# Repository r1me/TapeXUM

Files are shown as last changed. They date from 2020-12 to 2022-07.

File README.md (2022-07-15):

# TapeXUM
TapeXUM is a USB device that can read and write to cassettes of Commodore 16/64/VIC-20 (read and write) and ZX Spectrum (read only) format. It requires a Commodore datasette connected to it. This project is based on ZoomTape by Arnd Menge, a great idea and originally a part of OpenCBM package. TapeXUM uses Arduino Pro Micro and through hole components so it's a DIY friendly design.  
Huge thanks to Data/Tropyx for creating enclosure design for 3D printing!  

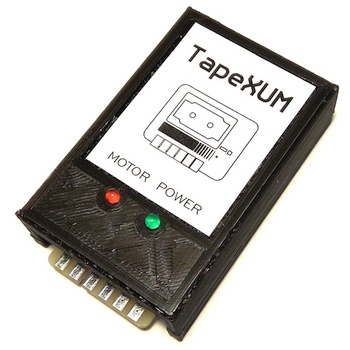
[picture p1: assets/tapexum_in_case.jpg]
TapeXUM in case


### Changes in software (since ZoomTape)
- modified device firmware to support Arduino Pro Micro
- added ability to continue tape capture even if stopped (before that, read was interrupted once datasette playback had stopped i.e. with Stop button)
- added azimuth adjustment feature (prepare your screwdriver)

### BOM
| Component  | qty |
| --- | --- |
| Arduino Pro Micro 5V | 1 |
| 1/4W Resistor for LEDs (~1K, depending on your preference) | 2 |
| 1/4W 1K Resistor | 1 |
| 1/2W 1.5k Resistor | 1 |
| 2N3904 Transistor | 1 |
| 2SD880 or 2SD313 Transistor | 1 |
| 3mm LED (i.e. green and red) | 2 |
| 6V8 Zener diode | 1 |
| 1N400x diode | 1 |
| 1uF electrolytic capacitor | 1 |
| 0.1uF electrolytic capacitor | 1 |
| Barrel jack DC connector 2.1/5.5mm or 2.5/5.5mm | 1 |
| 1x3 pin header 2.54mm and a jumper | 1 |
| 9VDC 500mA power supply with DC connector (center positive) | 1 |
| Micro USB cable | 1 |

### Download
Windows 7/10 64-bit libraries and tools: https://github.com/r1me/TapeXUM/releases/download/1.0/xum-installer-x64.zip  
Get PCB's from PCBWay: https://www.pcbway.com/project/shareproject/TapeXUM___Capture_and_write_Commodore_tapes_via_USB_device.html   
Gerber and Kicad files (hardware design): https://github.com/r1me/TapeXUM/tree/main/hardware  
Firmware for Arduino Pro Micro: https://github.com/r1me/TapeXUM/tree/main/firmware  
3D enclosure: https://www.thingiverse.com/thing:4659235  
OpenCBM: https://github.com/r1me/OpenCBM  

### Programming Arduino
`avrdude -p m32u4 -c avr109 -P comX -U flash:w:xum1541-PROMICRO_TAPE-v08.hex`

### License
TapeXUM follows same license for software as OpenCBM. PCB design of TapeXUM is free and shared under CERN OHW v2 (open hardware licence).

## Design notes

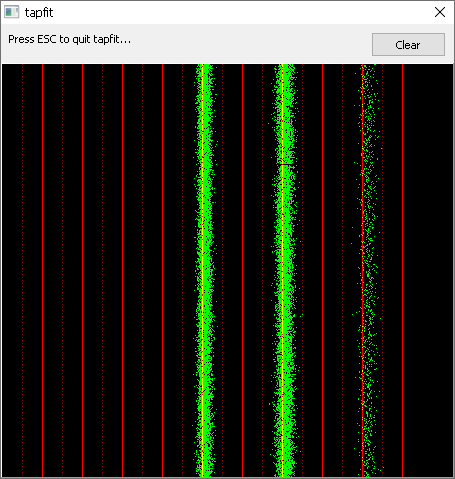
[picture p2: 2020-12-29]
assets/tapfit.png

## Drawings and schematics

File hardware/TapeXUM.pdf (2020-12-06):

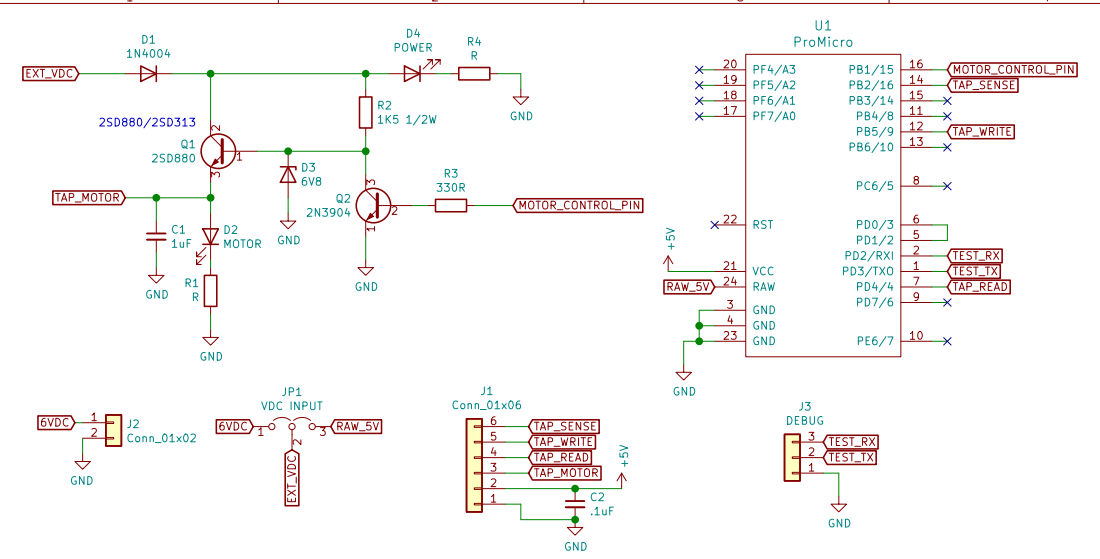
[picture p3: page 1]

File: TapeXUM.sch Sheet: / rime

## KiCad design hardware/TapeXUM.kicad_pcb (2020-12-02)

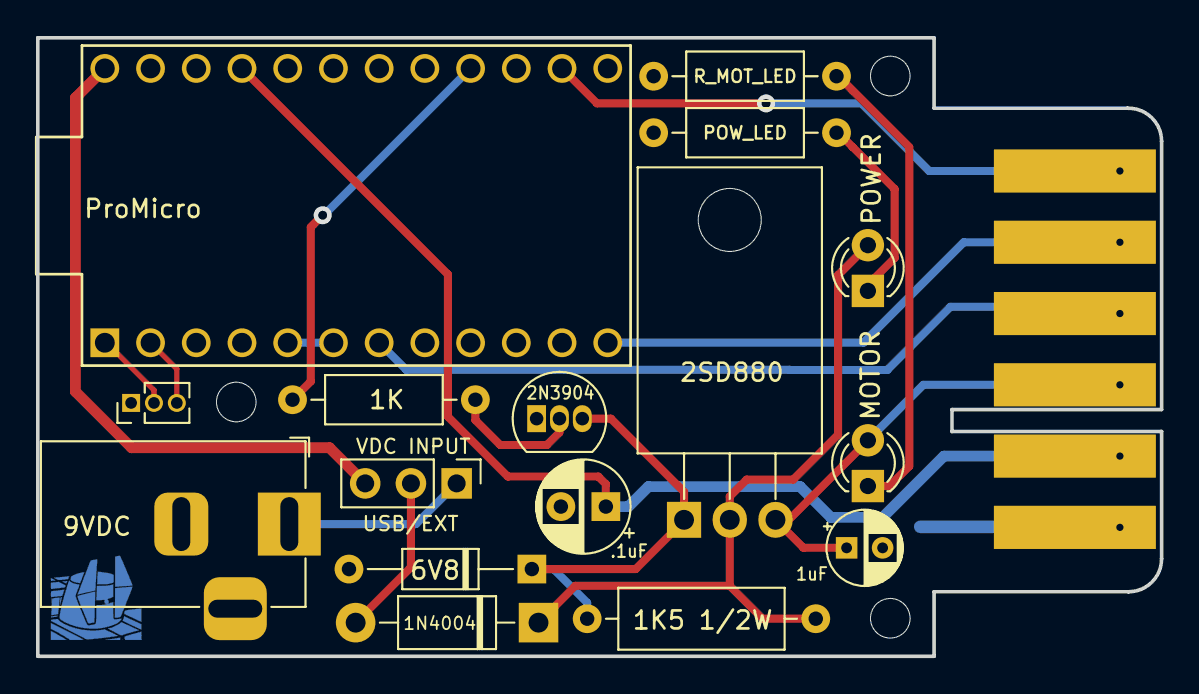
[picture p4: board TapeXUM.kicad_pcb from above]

Board: 2 copper layers, 62.4 x 34.4 mm, 17 parts (0 on the bottom side), 18 nets.

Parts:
C1: 1uF; CP_Radial_D4.0mm_P2.00mm
C2: .1uF; CP_Radial_D5.0mm_P2.50mm
D1: 1N4004; D_DO-41_SOD81_P10.16mm_Horizontal
D2: MOTOR; LED_D3.0mm
D3: 6V8; D_DO-35_SOD27_P10.16mm_Horizontal
D4: POWER; LED_D3.0mm
J1: Conn_01x06; conn_datasette2
J2: Conn_01x02; BarrelJack_Horizontal
J3: DEBUG; PinHeader_1x03_P1.27mm_Vertical
JP1: VDC INPUT; PinHeader_1x03_P2.54mm_Vertical
Q1: 2SD880; TO-220-3_Horizontal_TabDown
Q2: 2N3904; TO-92_Inline
R1, R4: R; R_Axial_DIN0207_L6.3mm_D2.5mm_P10.16mm_Horizontal
R2: 1K5 1/2W; R_Axial_DIN0309_L9.0mm_D3.2mm_P12.70mm_Horizontal
R3: 330R; R_Axial_DIN0207_L6.3mm_D2.5mm_P10.16mm_Horizontal
U1: ProMicro

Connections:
6VDC: J2.1, JP1.1
+5V: C2.1, J1.2, U1.21
EXT_VDC: D1.2, JP1.2
GND: C1.2, C2.2, D3.2, J1.1, J2.2, J3.1, Q2.1, R1.1, R4.1, U1.3, U1.4, U1.23
MOTOR_CONTROL_PIN: R3.1, U1.16
unnamed: D1.1, D4.2, Q1.2, R2.1
unnamed: D2.1, R1.2
unnamed: D3.1, Q1.1, Q2.3, R2.2
unnamed: D4.1, R4.2
unnamed: Q2.2, R3.2
unnamed: U1.5, U1.6
RAW_5V: JP1.3, U1.24
TAP_MOTOR: C1.1, D2.2, J1.3, Q1.3
TAP_READ: J1.4, U1.7
TAP_SENSE: J1.6, U1.14
TAP_WRITE: J1.5, U1.12
TEST_RX: J3.3, U1.2
TEST_TX: J3.2, U1.1

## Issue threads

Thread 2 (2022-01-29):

What is behind this crazy idea of use 0.1 uF electrolytic capacitor?

mesmariusz, 2022-01-29:
Hi :-)

What is behind this crazy idea of use 0.1 uF electrolytic capacitor?
[https://i.imgur.com/Gs0jLsC.png](https://i.imgur.com/Gs0jLsC.png)
[https://i.imgur.com/7Lc5MwK.png](https://i.imgur.com/7Lc5MwK.png)

Why didn't you use just standard unpolarized capacitor e.g. 100 nF / 50V ?

Is there seriously any reason to use 0.1 uF electrolytic capacitor?

mesmariusz, 2022-03-11:
Anybody here?

May I use just common unpolarised 100nF instead of electrolytic 0.1 uF ?

mesmariusz, 2022-03-16:
Ok, thank you very much for your feedback.

Closed 2022-03-16.

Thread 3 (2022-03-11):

Available .hex vs Pro-Micro-ATmega32U4-5-V-16-MHz - should it work on this hardware ?

mesmariusz, 2022-03-11:
Should the firmware:
https://github.com/r1me/TapeXUM/tree/main/firmware

work with this module:
https://shopee.pl/Baipestotoy-Pro-Micro-ATmega32U4-5-V-16-MHz-Wymie%C5%84-ATmega328-Arduino-Pro-Mini-i.550891774.12958189188

Is / should be the uC on this module compatibile with this .hex ?

r1me, 2022-03-16:
Hey, yes that's a right footprint Arduino Pro Micro (there are few other versions that wouldn't fit). The one you've linked will work correctly for this project.

Closed 2022-03-16.

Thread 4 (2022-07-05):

Any recommended way to flash .hex file to Arduino Pro Micro (Leonardo) ?

mesmariusz, 2022-07-05:
Hi.

Is there any recommended way to program .hex file to Arduino Pro Micro (Leonardo) ?

I have the issue as below:

https://i.imgur.com/NklN7Ol.png

r1me, 2022-07-06:
`avrdude -p m32u4 -c avr109 -P comX -U flash:w:xum1541-PROMICRO_TAPE-v08.hex`

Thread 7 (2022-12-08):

9VDC power supply seems too high

Kalidomra, 2022-12-08:
The BOM lists a 9VDC power supply. The schematic shows 6VDC. Which is the correct supply voltage?

r1me, 2022-12-09:
Hi, motor power part of TapeXUM design resembles the C64 schematic in which a 9V goes through a 6.8V zener diode, thus delivering slightly above 6V to a datasette motor. A 9VDC power supply connected to TapeXUM is used to create that voltage in exact same manner.

Closed 2022-12-09.

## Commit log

2020-12-02 Added hardware design in Kicad and gerber files
    [TapeXUM-B_Cu.gbl, TapeXUM-B_Mask.gbs, TapeXUM-B_Paste.gbp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]
2020-12-02 Add sticker design for 3D enclosure
2020-12-02 Add ZIP file for gerbers
2020-12-06 Add schematics in PDF format

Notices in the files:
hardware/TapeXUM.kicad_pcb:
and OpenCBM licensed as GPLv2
